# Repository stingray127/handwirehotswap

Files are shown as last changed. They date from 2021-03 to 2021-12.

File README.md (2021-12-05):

# handwirehotswap
A 3D printed, Solderless Hot Swap Socket to build keyswitch matrixes

Link to the original Thingiverse Post: https://www.thingiverse.com/thing:4791318

Hop into the "Matrix" or "Socket" folders for photo guided assembly instructions

## v4 is out!

**Orientation of the STL file is not correct. Print this with diode slot facing up**

v4 brings significant improvements, including:
- Easier to print
  - Important dimensions are now printed on the top face, reducing problems caused by first layer horizontal expansion
  - Much easier to press the switch into the socket now
- Improved robustness of row wire connection
  - Row wire can now be clamped down onto the diode wire
- Faster to assemble / put in diode
  - Less precision required, more brute force expected
- Better method of connecting pin and diode
  - v3 had a nasty tendency to crush the upper switch pin, especially considering the amount of force required to put the switch into a v3 socket.
  - New design has an escape path for the pin if misaligned, and a better way of making electrical connection overall.

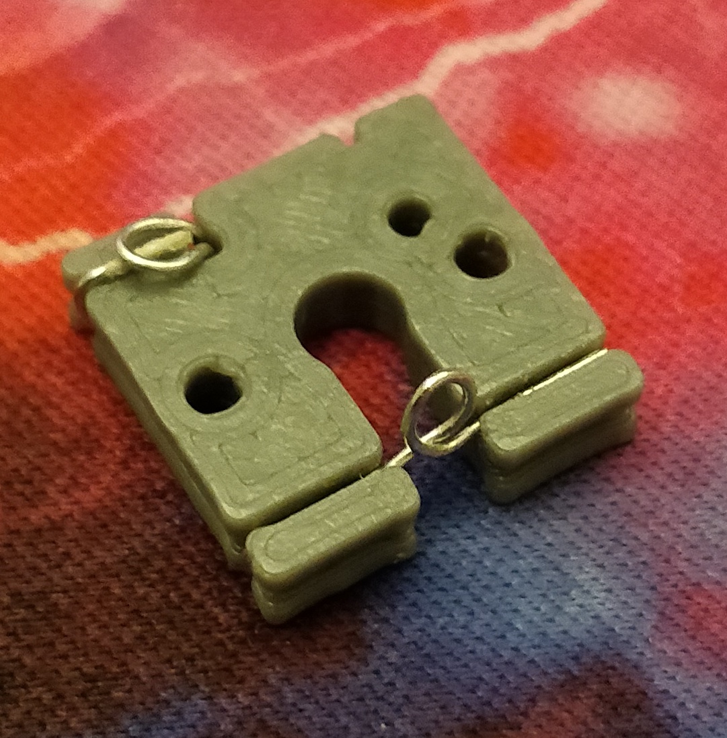
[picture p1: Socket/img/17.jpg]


## Other hardware notes

Diode Legs: 25 SWG

Solid Core Wire: 24 SWG

24 SWG is ~0.558mm diameter, anything around .5mm dia should work fine.

If thicker solid core wire is used, it is advised to go into the code and adjust the size of the row wire channel and column pin hole. Thingiverse Customizer might also work but I have not tested it much.

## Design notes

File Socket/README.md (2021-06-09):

# Building Sockets

Lay diode in the diode slot, making sure to use the correct orientation

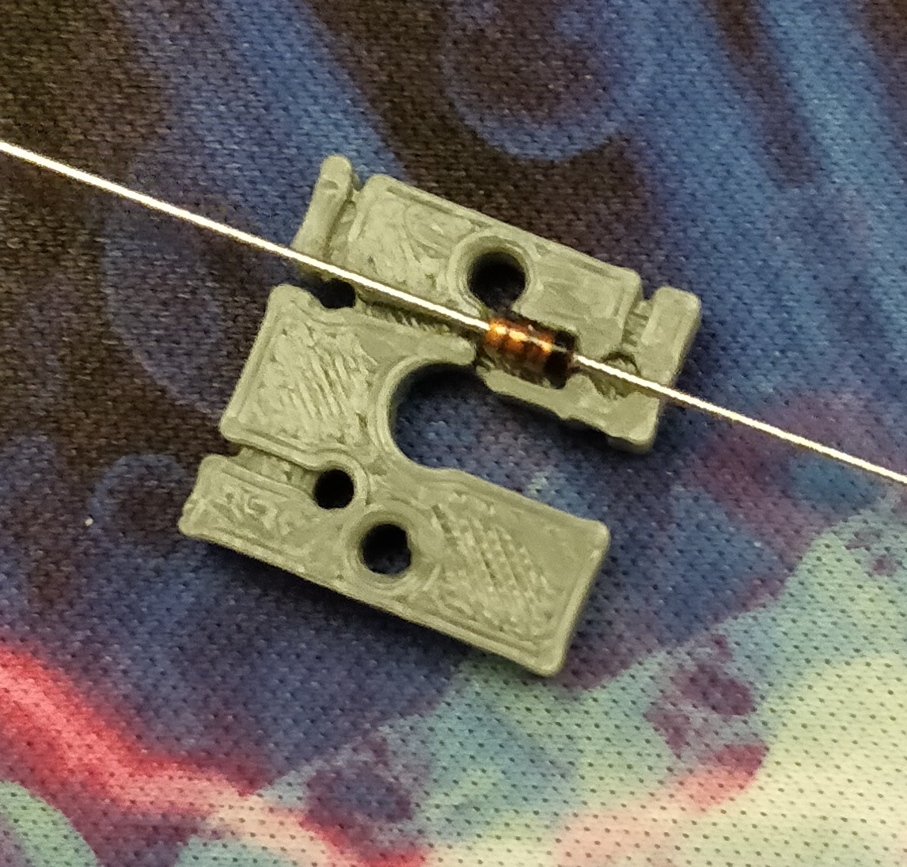
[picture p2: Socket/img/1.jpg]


Press the diode and wire into their slots

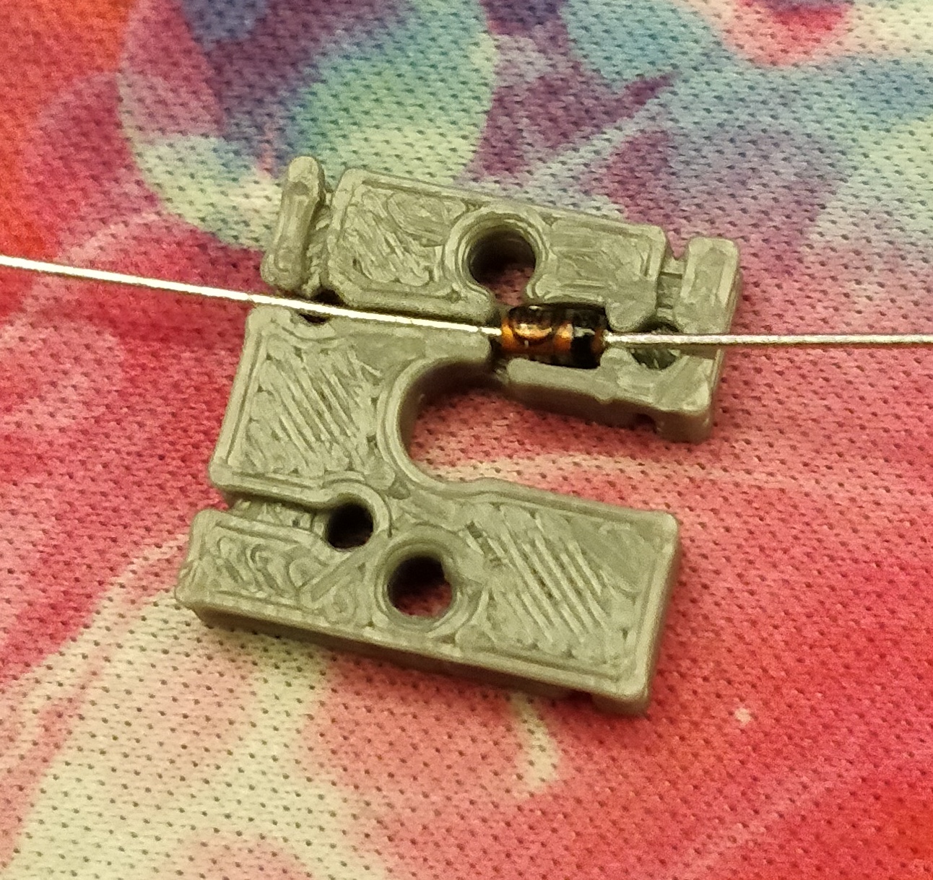
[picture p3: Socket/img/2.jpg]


Grab the diode leg and bend it up to form a tight 90 degree angle

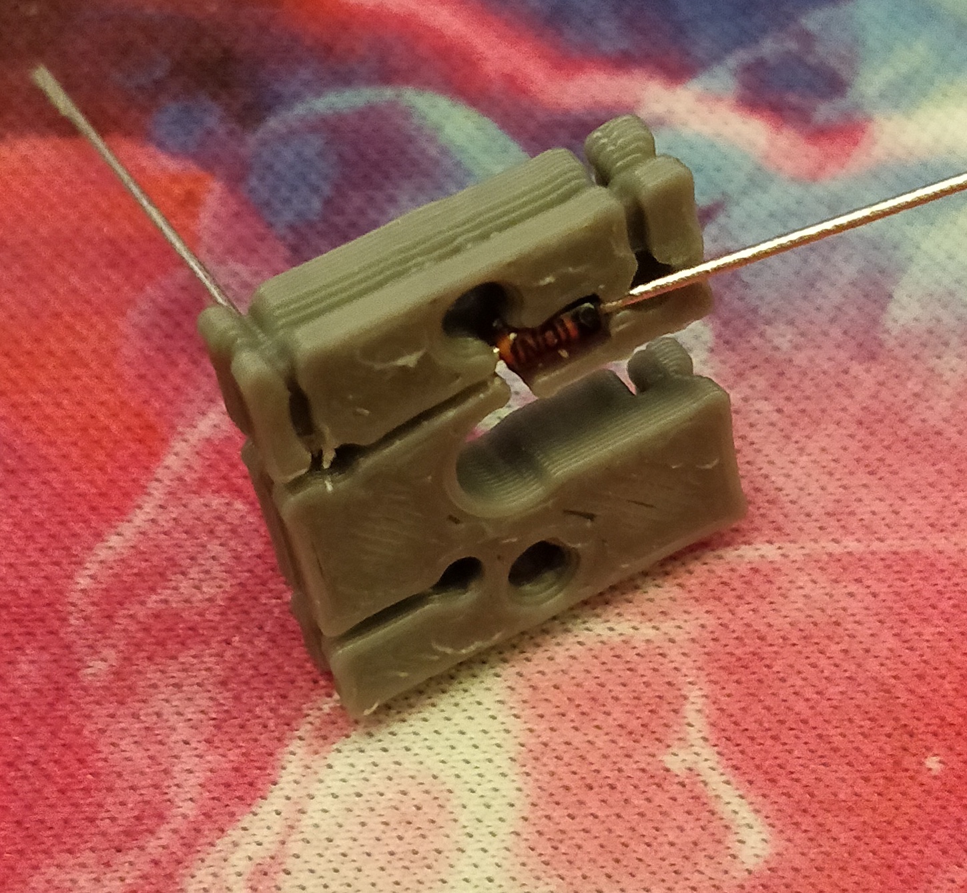
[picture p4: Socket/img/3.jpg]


Also bend the other leg into the slot. Easier to work if that wire is out of the way

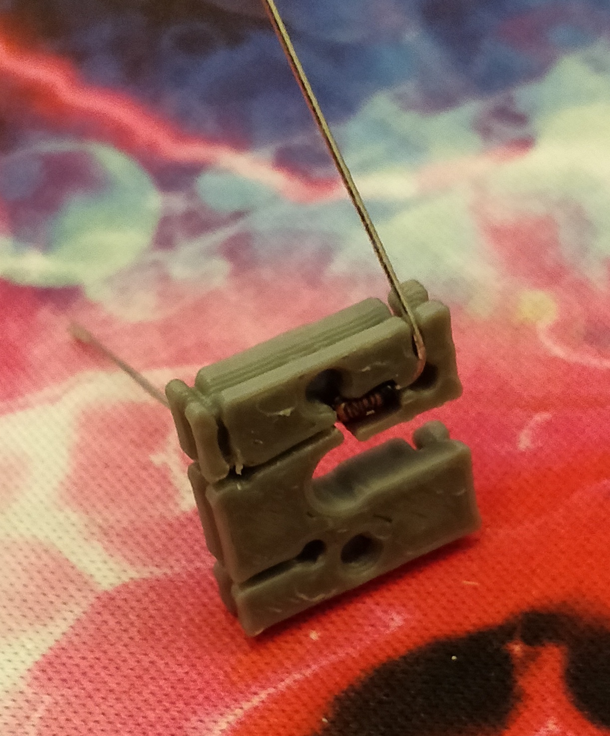
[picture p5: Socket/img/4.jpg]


Using a small round dowel like a precision screwdriver shaft, bend the wire leg 180 degrees around the shaft

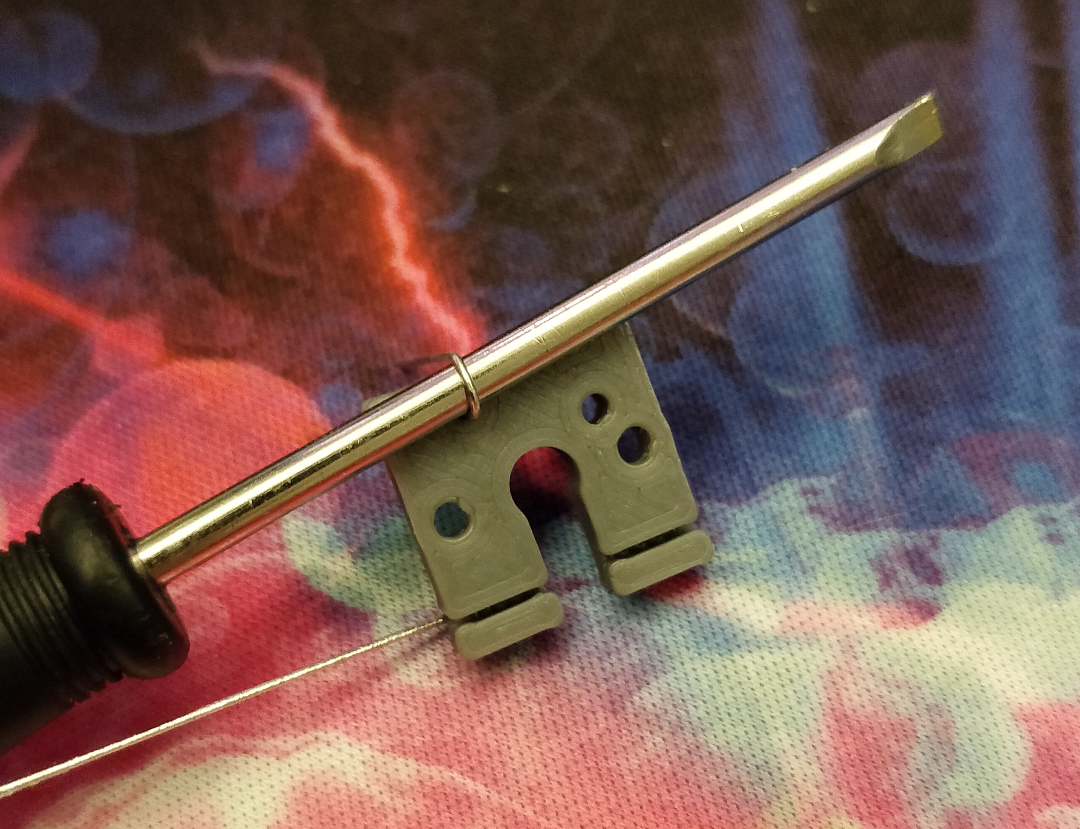
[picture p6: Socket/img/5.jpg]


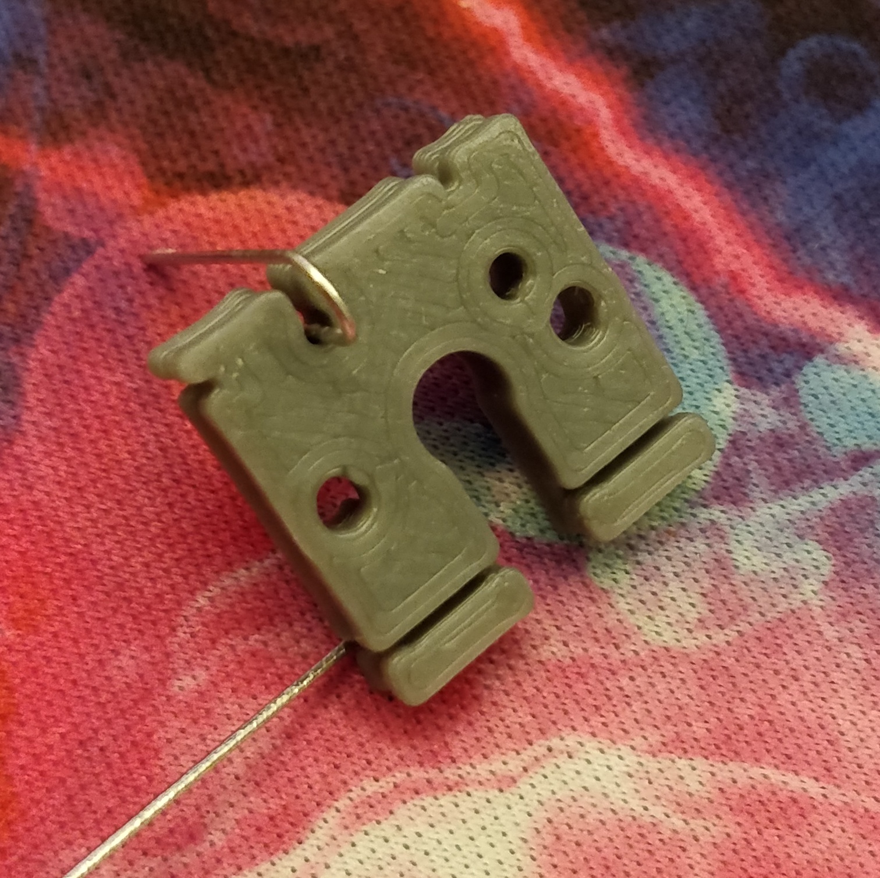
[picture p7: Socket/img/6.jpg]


Using fingers, crush the bend into a teardrop shape

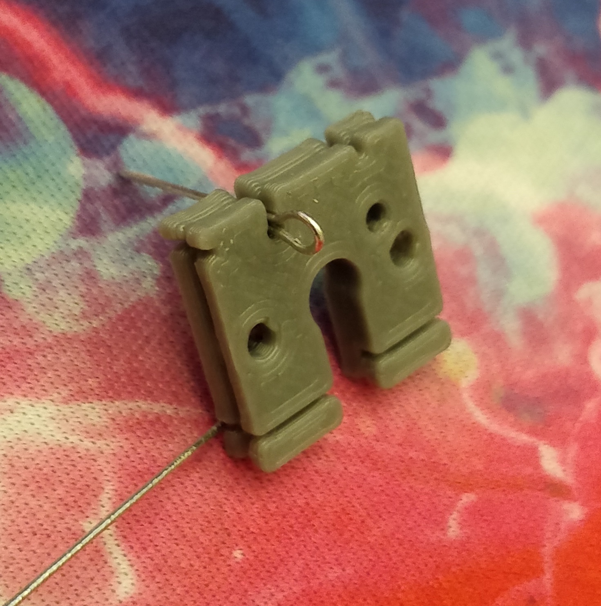
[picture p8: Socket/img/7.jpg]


Wrap the remaining diode leg wire around the body using 2x 90 degree angle bends

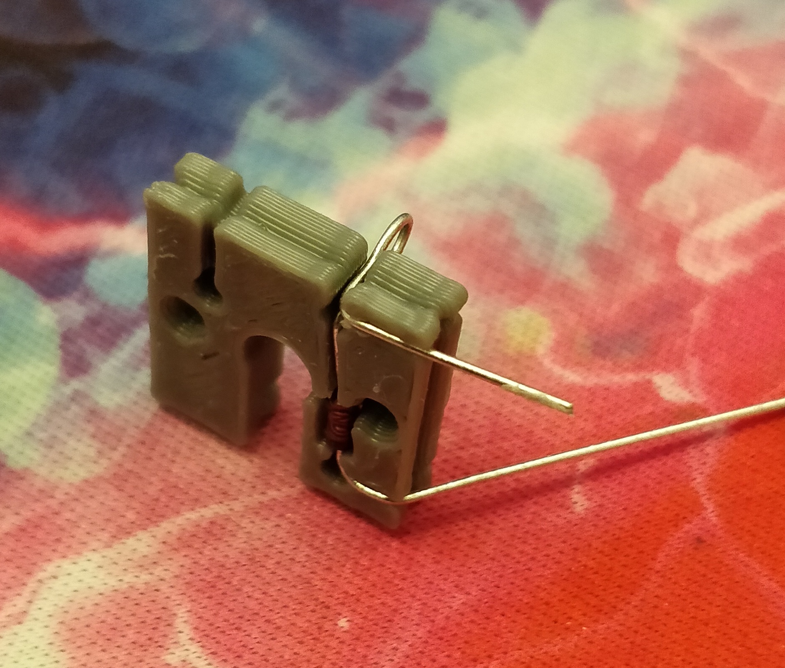
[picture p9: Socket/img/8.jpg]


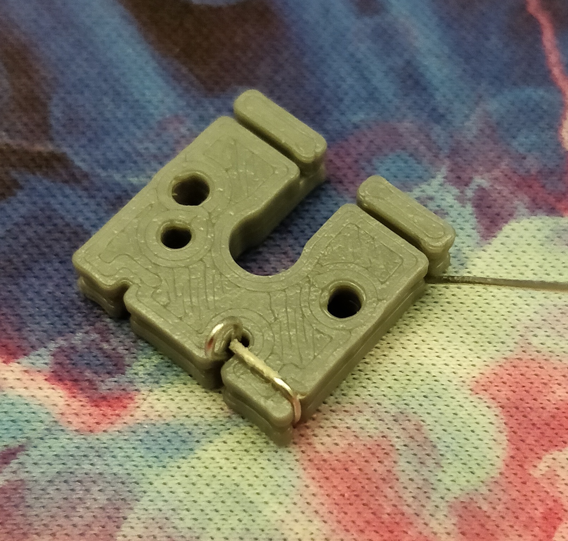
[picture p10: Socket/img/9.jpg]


Fold the teardrop onto the wire to keep it in place

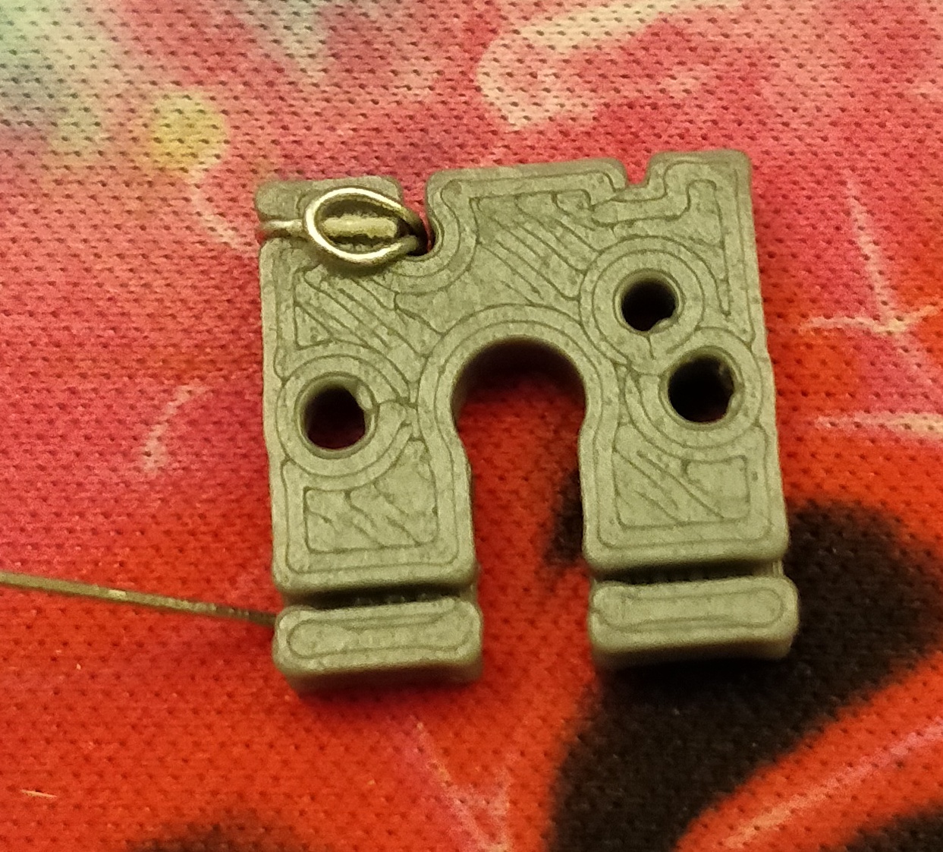
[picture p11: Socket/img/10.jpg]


Using a fingernail, force the other diode leg into the row wire channel

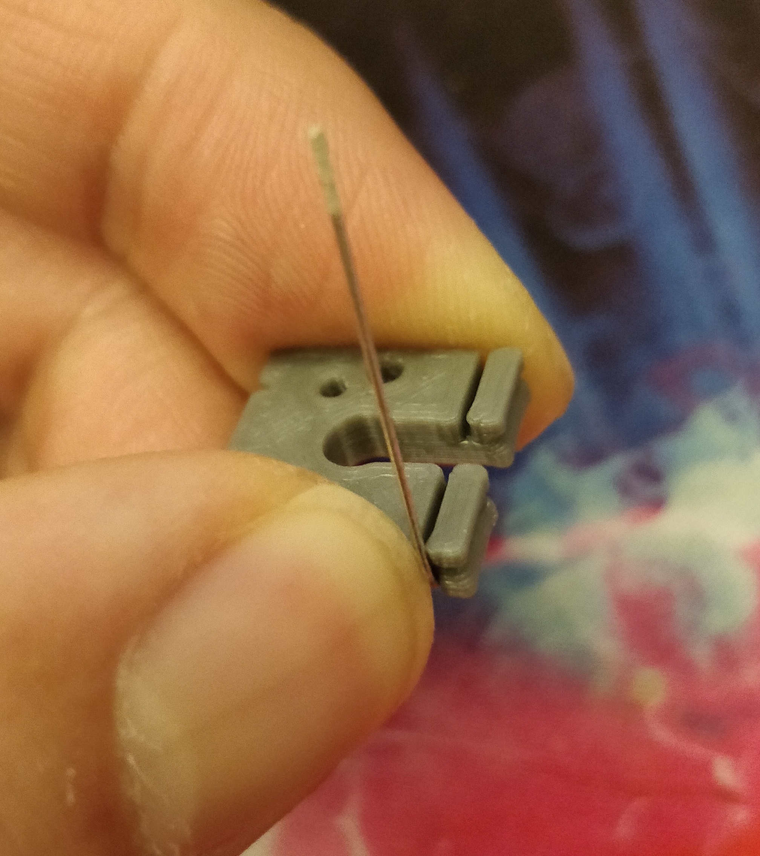
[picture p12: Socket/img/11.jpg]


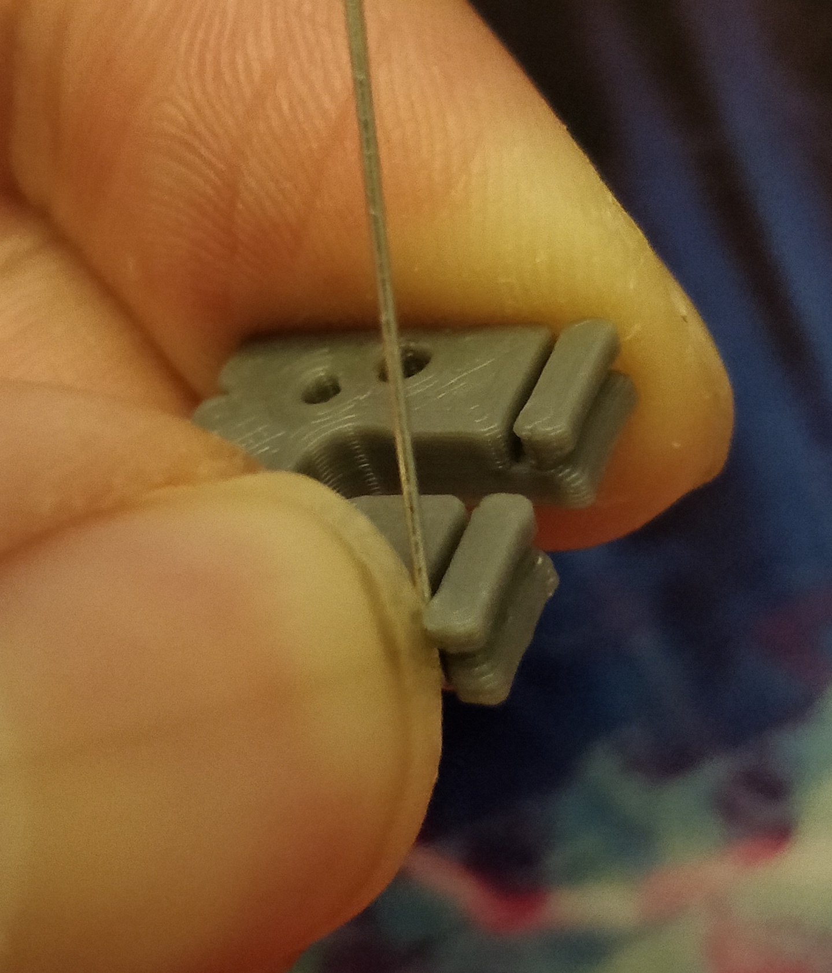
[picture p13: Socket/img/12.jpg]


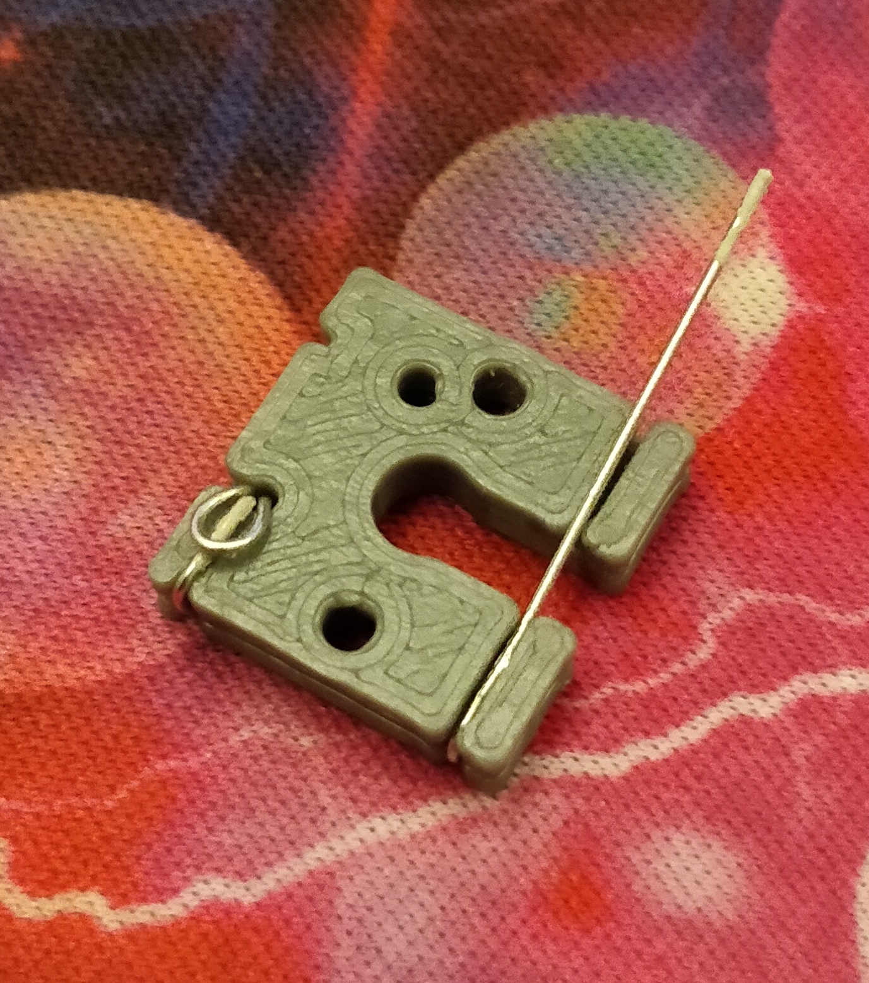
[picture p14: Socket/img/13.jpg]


Using the screwdriver, wrap the wire 360 degrees around the shaft. Its okay to translate while rotating to more easily make the full rotation

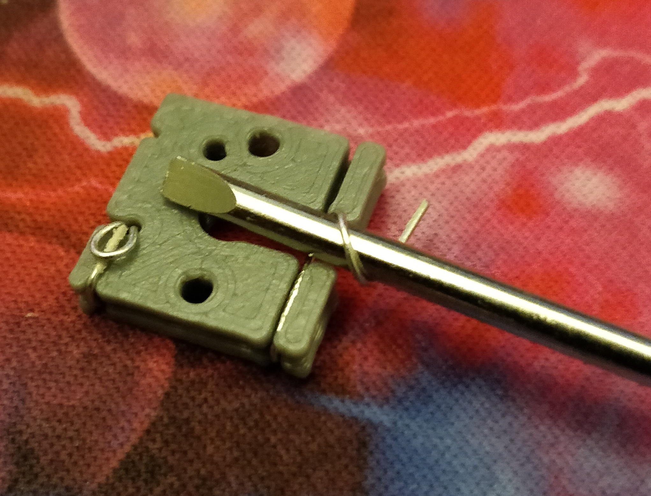
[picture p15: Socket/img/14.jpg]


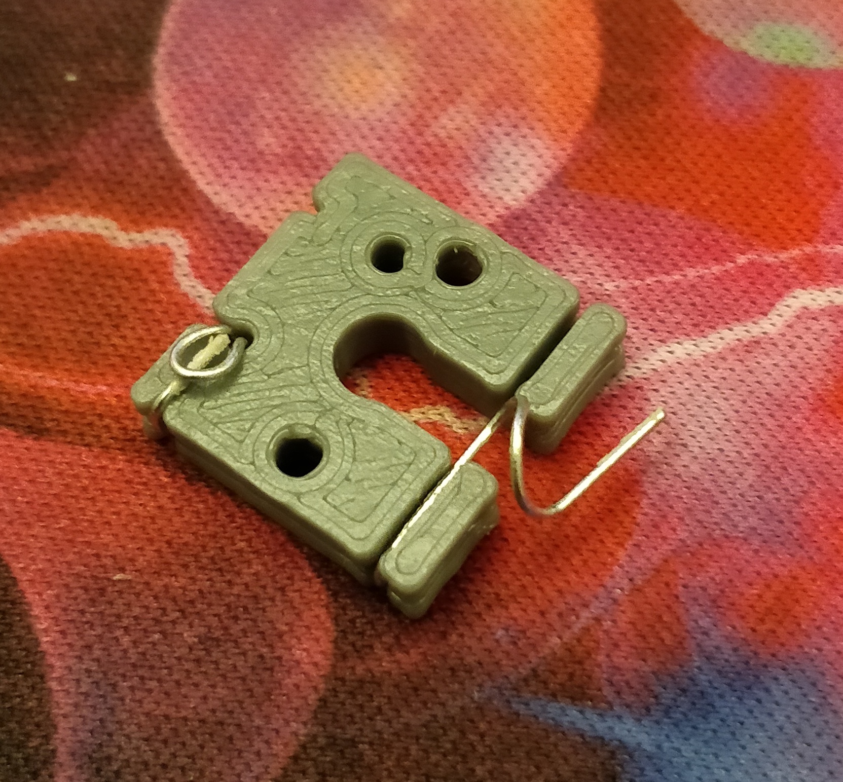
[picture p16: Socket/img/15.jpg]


Form a loop using the bends, trying to keep the loop centered

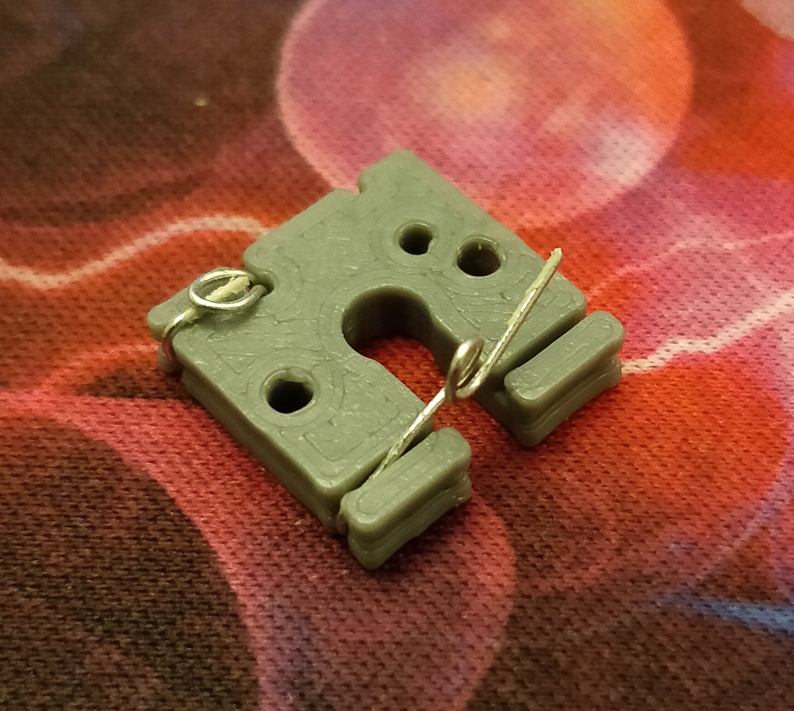
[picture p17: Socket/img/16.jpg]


Seat the remaining diode wire into the row slot



Thats how you make a socket! Perform some switch fit tests to make sure everything is in order.

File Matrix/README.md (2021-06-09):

# Building the Matrix

The best way to make the matrix is to alternate wiring columns and rows, weaving the matrix together one row at a time.

In this picture, I just did the first column wire connections for the first row of sockets. I then connected all the sockets together using a single row wire. The next step would be to do the column connections of the second row of sockets.

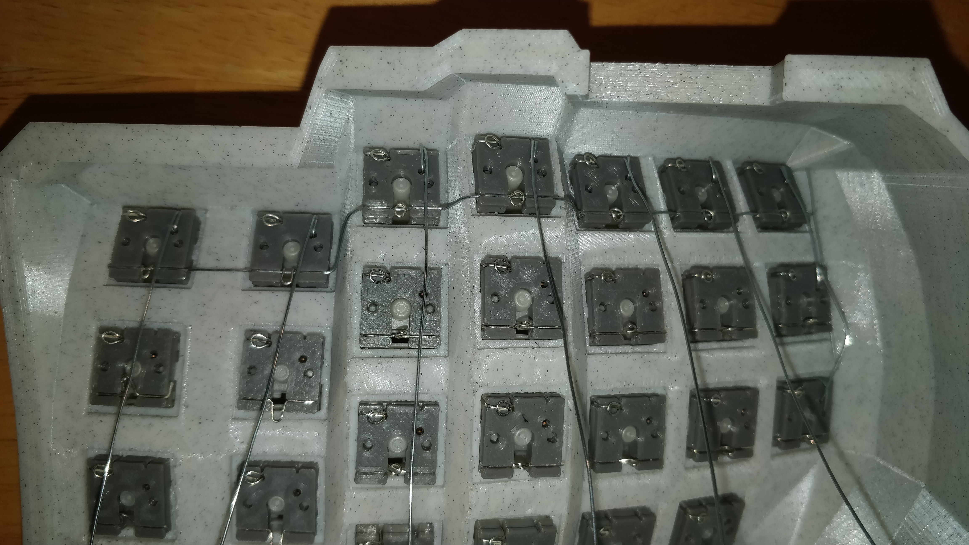
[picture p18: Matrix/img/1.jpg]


## Columns

We need to make a 90 degree bend near the right pin. A good rule of thumb (oops) is to make the bend at the switch pin

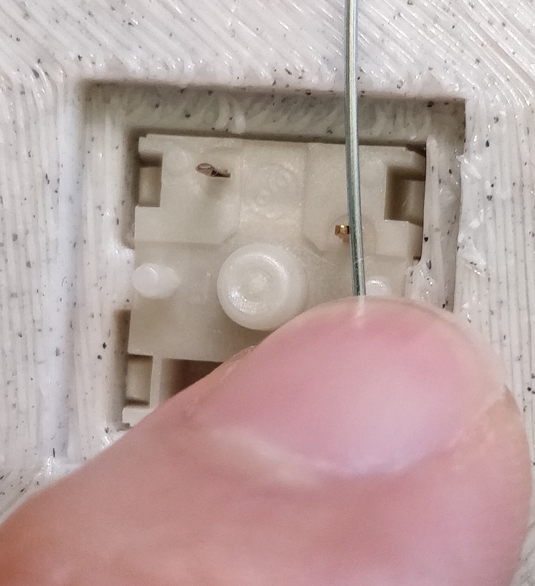
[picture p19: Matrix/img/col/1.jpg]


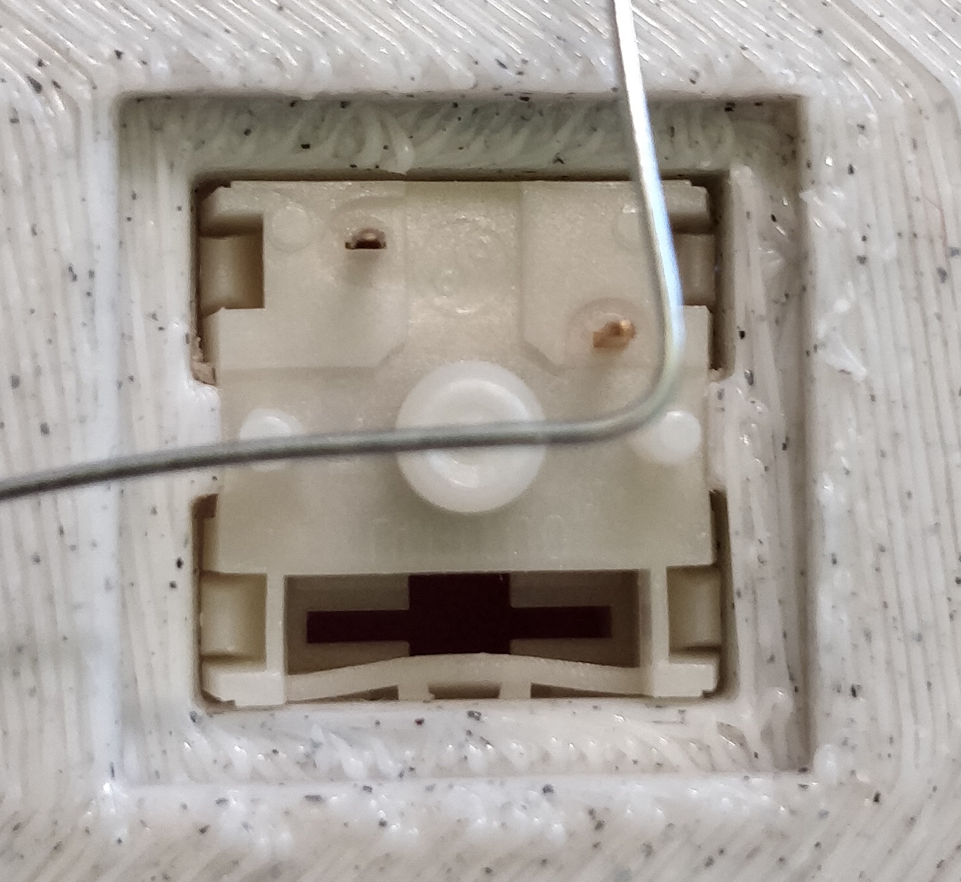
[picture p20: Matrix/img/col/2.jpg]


Thread the column wire into the top face of the socket, in the appropriate hole

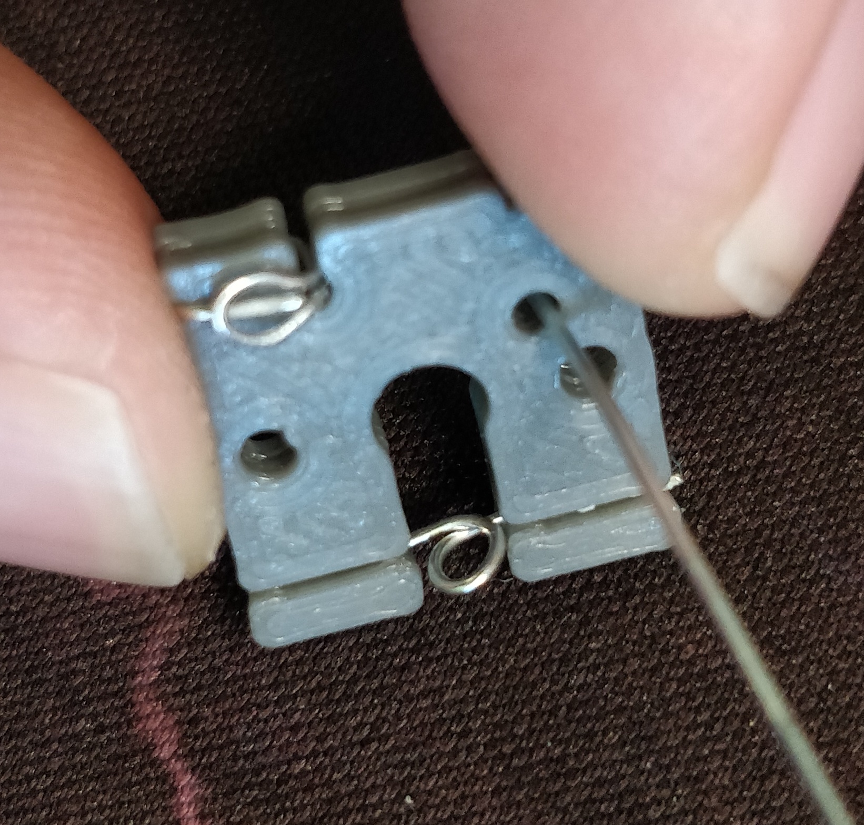
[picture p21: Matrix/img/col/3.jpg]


Seat the 90 degree bend in the wire channel

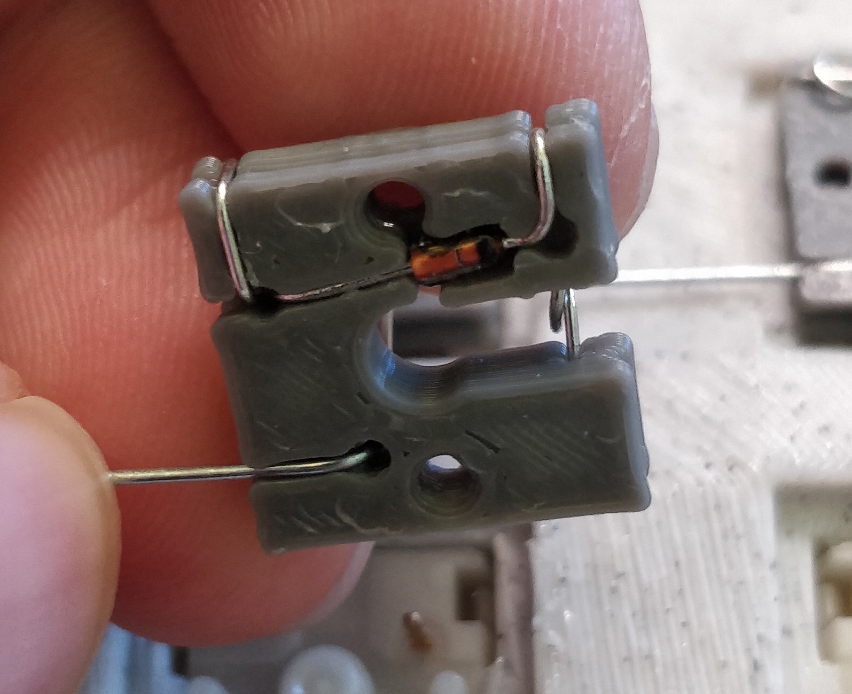
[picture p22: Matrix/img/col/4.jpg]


Make 2x 90 degree bends around the body, locking the socket body into the wire loop. This is also a great place to drop a bead of solder to permanently hold the matrix together 

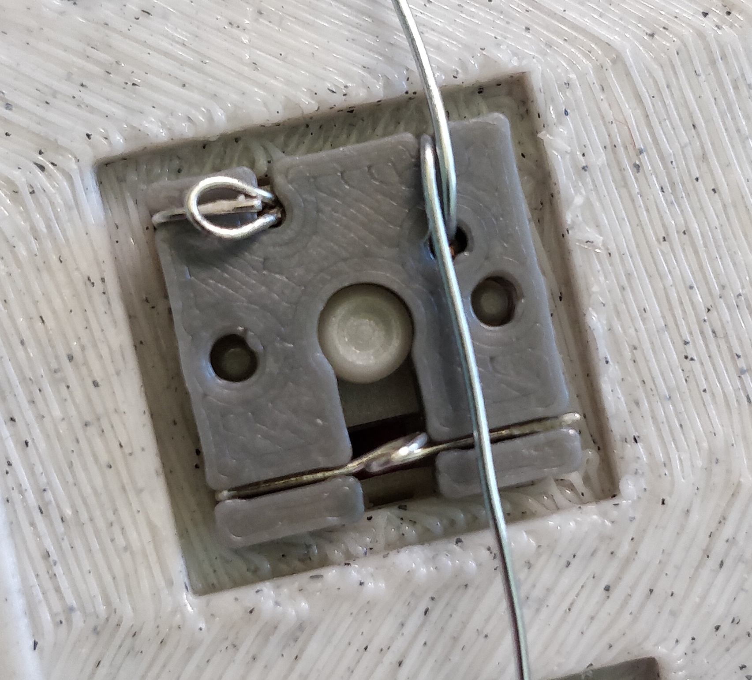
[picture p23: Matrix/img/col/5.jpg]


## Rows

Wire up the columns as per the above instructions

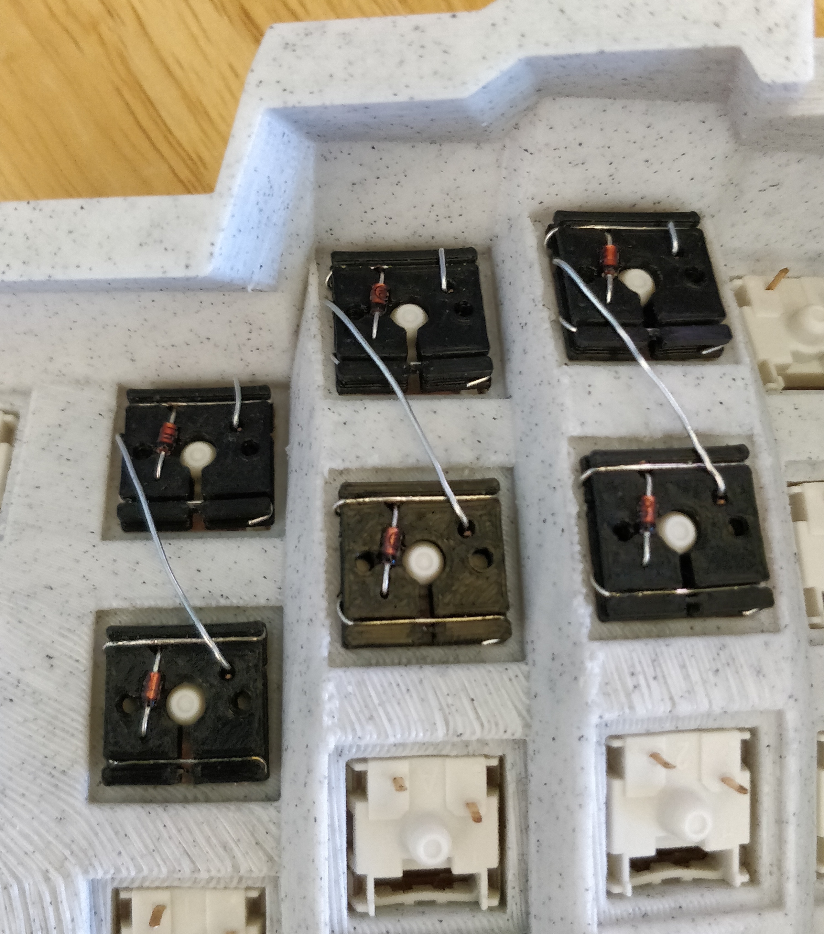
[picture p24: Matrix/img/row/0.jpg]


Snake a length of solid core wire across the entire row, making sure to cross UNDER the column wires. The difficulty of this will depend on how weird your board is and how tightly you wired the columns. If you use the weaving method as suggested at the top of this README, this step should be easy

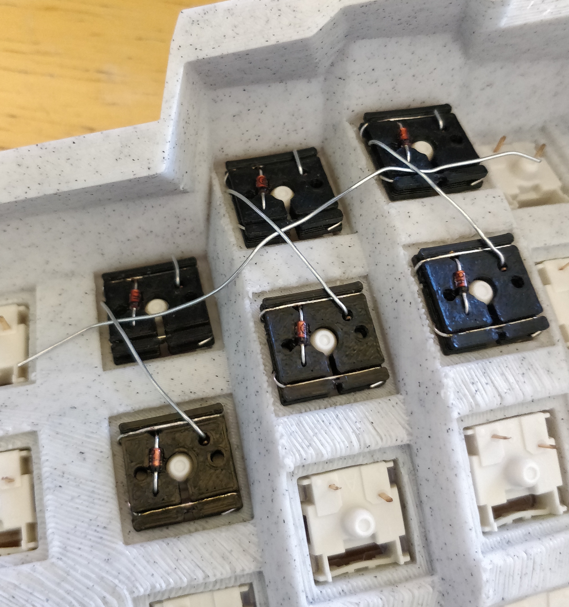
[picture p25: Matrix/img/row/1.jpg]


Position the wire over the bottom wire channel



Stab the wire into the channel using a flathead screwdriver or fingernails



Position the wire



Stab the wire in. Position the next wire



Stab the wire in



Fold the loop of wire in the gap over the row wire to form a secure connection. This is also a great place to drop a bit of solder for a permanent connection.



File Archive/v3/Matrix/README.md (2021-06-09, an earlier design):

# Building the matrix

## Wiring a Matrix Col

1. Put all the switches into the board body



2. You will need many socket pieces and a long length of solid core wire



3. Bend a small section of the solid core wire into a 90 degree angle



4. Insert the short piece into the pin hole of the hot swap socket. The rest of the wire can exit from left or right of the socket body, but for this tutorial it will exit like in the image. Press the solid core wire deep into the wire channel



5. Pop the socket onto the switch. Do this carefully, and make sure the switch pin isn't bent



6. Fold the wire towards the next switch pin



7. Make a tight 90 degree bend a small distance away from the switch pin



8. Thread another hot swap socket onto the wire. Note the orientation of the socket as the wire goes in



9. The socket should slide past the 90 degree bend



10. Press the wire into the channel



11. Pop the socket onto the switch. Again, be careful as to not bend the switch pin



12. Rinse and repeat until you're done with the column. Trim any excess wire as necessary







## Wiring a Matrix Row

1. Wire up the columns as per the above instructions



2. Snake a length of solid core wire across the entire row, making sure to cross UNDER the column wires. The difficulty of this will depend on how weird your board is and how tightly you wired the columns.



3. Position the wire over the bottom wire channel. This can be done by hands or with a tool



4. Stab the wire into the channel using a flathead screwdriver. Be sure to press along the entire wire channel to maximize the chance of forming a solid electrical connection



5. Position the wire



6. Stab the wire in. Position the next wire



7. Stab the wire in



8. Finished Result



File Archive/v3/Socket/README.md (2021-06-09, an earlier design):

# Building a Socket

1. Lay the diode in the diode channel



2. Use your nail to mark where this diode leg would bend into the hole



3. Bend the diode leg to 90 degrees. Ideally, the radius of the bend should be small



4. Slot the bent leg into the hole. Use your fingernail and mark where the other diode leg would bend into the hole



5. Bend the diode leg to 90 degrees. Again, try to make the radius of the bend small



6. Slot diode into the socket



7. Turning the socket over, bend the legs 90 degrees into their wire channels. Use a screwdriver to force them into the slot if necessary



8. Bend one leg so it rests over the top wire channel



9. Use a flathead screwdriver to force the wire into the wire channel. Notice how the wire appears recessed in this photo



10. Bend the other leg so it rests over the bottom wire channel



11. Use a flathead to push the wire to the bottom of the channel. This wire will be a loose fit in the bottom wire channel





13. Do a fit check on the socket. Ideally, the switch pin in the green circle squeezes itself between the 2 wires



14. Bend the remaining leg wires around the body



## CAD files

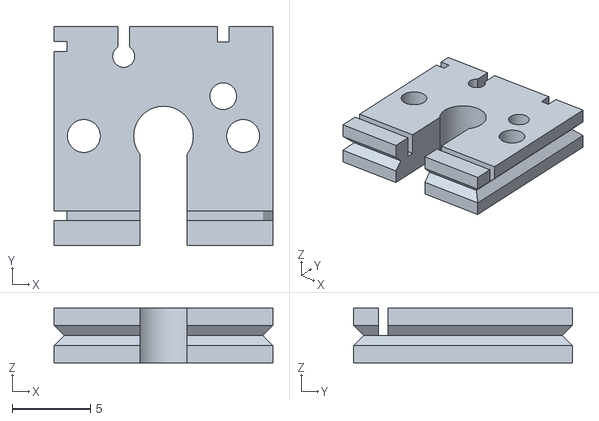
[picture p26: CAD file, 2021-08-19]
HSSv4.4.stl
14.0 x 14.0 x 3.50

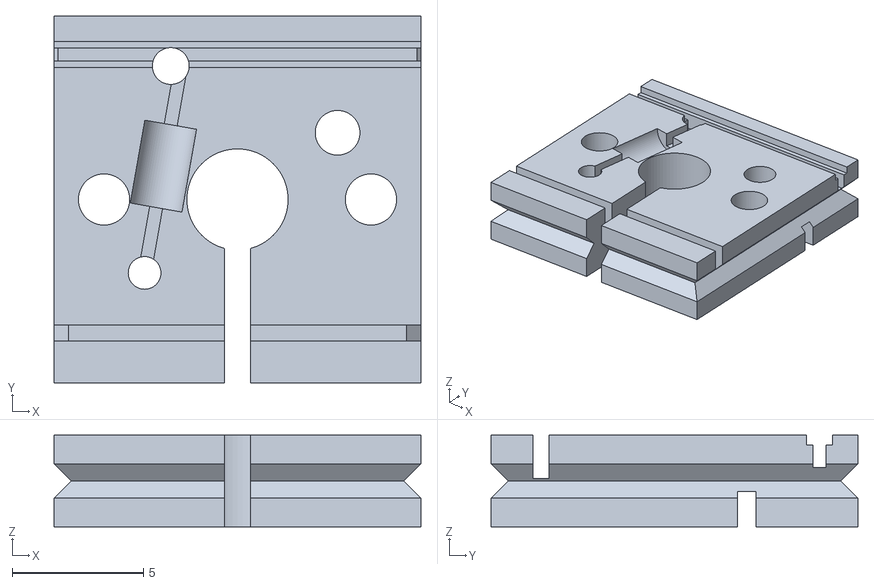
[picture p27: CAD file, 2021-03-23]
HSSv3.9.stl
14.0 x 14.0 x 3.50

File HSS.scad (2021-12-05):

$fn = 64;
grid = 1.27;

diode_gauge_mm = 0.508;
wire_gauge_mm = 0.559;

pin2 = [-2*grid, 4*grid, 1.4];
pin1 = [3*grid, 2*grid, 1.7];

stem = [0, 0, 3.80];
peg1 = [-4*grid, 0, 2.1];
peg2 = [4*grid, 0, 2.1];
base = [11*grid, 11*grid, 3.5];

diode_dia = diode_gauge_mm * 0.98;
wire_dia = wire_gauge_mm * 1.1;

diode_angle = -6;

// diode_mock();

difference(){
    make_body();

    left_pin_wire_slots();

    right_pin_wire_slots();

    diode_slot();
}

module make_body(){
    difference(){
        translate([0, 0, 0]){
            cube([base.x, base.y, base.z], center = true);
        }

        // Side Slots for removal
        translate([7.75, 0, 0])
            rotate([0, 45, 0])
                cube([2, 20, 2], center = true);

        translate([-7.75, 0, 0])
            rotate([0, 45, 0])
                cube([2, 20, 2], center = true);

        translate([0, 7.75, 0])
            rotate([45, 0, 0])
                cube([20, 2, 2], center = true);

        translate([0, -7.75, 0])
            rotate([45, 0, 0])
                cube([20, 2, 2], center = true);

        // Main Stem Clamp
        translate([stem.x, stem.y, 0]){
            cylinder(h=base.z*2, d=stem[2], center = true);
        }

        translate([0, -5, 0]){
            cube([3, 10, base.z*2], center = true);
        }

        // PCB Mount Pegs
        translate([peg1.x, peg1.y, 0]){
            cylinder(h=base.z*2, d=peg1[2], center = true);
        }

        translate([peg2.x, peg2.y, 0]){
            cylinder(h=base.z*2, d=peg2[2], center = true);
        }

        // Switch Pins
        translate([pin2.x, pin2.y, 0]){
            cylinder(h=base.z*2, d=pin2[2], center = true);
        }

        translate([pin1.x, pin1.y, 0]){
            cylinder(h=base.z*2, d=pin1[2], center = true);
        }

    }
}

module left_pin_wire_slots(){
    // Diode Pin Wire Channels
    translate([-2*grid, 5*grid, 0])
        cube([1.5*diode_dia, 3, base.z*2], center = true);

    translate([-4*grid, 4.5*grid, -base.z/2])
        cube([5, 1.25*diode_dia, 3*diode_dia], center = true);

    translate([-5.25*grid, 4.5*grid, 0])
        cube([1, 1.25*diode_dia, base.z*2], center = true);

    translate([0, -4*grid, base.z/2])
        cube([20, wire_dia, base.z], center = true);
    
    translate([-5.25*grid, -4*grid, 0])
        cube([1, wire_dia, base.z*2], center = true);
    
    translate([-4*grid, -4*grid, -base.z/2])
        cube([4, wire_dia, 3*diode_dia], center = true);

}

module right_pin_wire_slots(){
    translate([pin1.x, 4*grid, -base.z/2])
        cube([1.2*wire_dia, 4*grid, 3*wire_dia], center = true);
    translate([pin1.x, 5.5*grid, 0])
        cube([1.2*wire_dia, 2, base.z], center = true);
}

module diode_slot(){
    union(){
        // Diode Body + Other Leg
        translate([-2.45*grid, -1.5*grid, -0.75])
            rotate([0, 0, diode_angle]){
                cube([2.0, 3.5, 2.1], center = true);
            }
        translate([-2.45*grid, -1.5*grid, -base.z/2])
            rotate([0, 0, diode_angle]){
                translate([0, 2, 0])
                    cube([diode_dia, 11, 2.5], center = true);
                translate([0, -3.25, 0])
                    cylinder(h=2.5, d=1.75, center = true);
            }
    }
}

module diode_mock(){
    translate([-2.45*grid, -1.5*grid, -0.75])
        rotate([0, 0, diode_angle])
            rotate([90, 0, 0]){
                cylinder(h=3.2, d=2, center = true);
                cylinder(h=100, d=diode_dia, center = true);
            }
}

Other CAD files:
HSSv4.3.stl
Archive/HSSv4.3.stl

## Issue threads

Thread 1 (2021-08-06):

Suggestion of small addition to Readme

DavidCarpus, 2021-08-06:
I needed to adjust model a little to fit the diodes I had. Went to adjust the scad file and was missing the chamfer. It may be good to include a reference to https://github.com/revarbat/BOSL if adjustments to the model are needed. Just as an FYI: I also remove some of the additional side channels that no longer seem to be needed to increase the print strength.

stingray127, 2021-08-19:
Removed chamfer() references, I don't think they were contributing much.

Closed 2021-08-19.

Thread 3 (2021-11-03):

Non insulated wire

eirikm, 2021-11-03:
What is the diameter of the non isolated wire you are using? What is it called? And where can I buy it?

stingray127, 2021-11-03:
I used aluminum solid core 24 SWG wire, and I think the specific roll I bought was from Home Depot for hanging picture frames or something random.

24 SWG is ~0.558mm diameter, anything around .5mm dia should work fine.

You can always modify the .scad code to adjust the wire channel dimensions as you see fit.

Closed 2021-11-08.

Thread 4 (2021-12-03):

Readme addition: wiring gauge

pfn, 2021-12-03:
Hi, this design is so very nice, and I built one side of my keyboard with it.... but, I used 26awg solid wire, as a result, I have to shim to crap out of one side of each of my keyswitches to ensure a good electrical connection. For those that come after, could a mention about recommended wiring gauge be added? I did deeper diving into your thingiverse link, and it is mentioned there, but consider this github to be your one-stop-shop, it would be great to have it mentioned.

I'm going to be building my second side of keyboard with 26awg still (because I'm too lazy to go to the store to buy new wire), but I will triple wrap the other terminal to ensure a good connection.

Thanks @stingray127 !

stingray127, 2021-12-05:
Added wire gauges to the README. Good luck with the build!

Closed 2021-12-05.

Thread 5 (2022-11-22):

About the assembly of the key swiches

fyang93, 2022-11-22:
Thank you for the brilliant work first.
I am planning to build a keyboard with your design but I got very confused after reading your build log.
So in my understanding, the side of diode should be hided in the case, as shown in [this picture](https://github.com/stingray127/handwirehotswap/blob/main/Matrix/img/row/0.jpg), where the key swiches are attached to the opposite side, the side without the diode.
But weirdly, in [another picture](https://github.com/stingray127/handwirehotswap/blob/main/Matrix/img/row/7.jpg), the key swiches are inserted underneath but attached to the side with diode slot.
This really confused me a lot, since I don't have any experience building a keyboard before. I would appreciate that if you may kindly give me some hints.

Closed 2024-10-26.

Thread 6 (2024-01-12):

What diode is used for this socket?

sebramirez44, 2024-01-12:
So basically i'm just getting into handwiring and I got these [diodes](https://www.amazon.com/100-Pieces-1N4148-Switching-High-Speed/dp/B079KJ91JZ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,aps,126&sr=8-3&linkCode=sl1&tag=joescotto-20&linkId=8d0ac8a6c72fbd5e2fb206aa45384cae&language=en_US&ref_=as_li_ss_tl) but they don't fit in the case, basically I just wanna know what's the actual diode used in this socket?

stingray127, 2024-01-22:
According to my digikey order I ordered a DO-35 package diode. I think the part code even matches yours. When you printed the part, did you orient the model so the diode pocket faces upwards?

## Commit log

2021-03-23 Wrote up some instructions
    [HSS.scad, HSSv3.9.stl]
2021-06-09 Added scad and v4.3 STL
    [HSS.scad, HSSv3.9.stl, HSSv4.3.stl]
2021-06-09 socket images
2021-08-19 removed chamfer()
    [HSS.scad, HSSv4.3.stl, HSSv4.4.stl]
2021-09-22 Remove unused variable hzExpComp
    [HSS.scad]
